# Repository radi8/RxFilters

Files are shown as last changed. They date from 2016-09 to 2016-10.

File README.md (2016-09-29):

# RxFilters

This is a first iteration of a set of high pass filters for a receiver. The filters are to be used in conjunction with the transmit low pass filters to form a bandpass filter which can be of variable width depending on the HP/LP combination selected. The advantage of this is that the Rx bandwidth can be wide (up to the Tx LP frequency) to enable skimming of frequencies up to the Tx frequency. I will be looking at diode switching of the filters in the future as this will give the option of developing smart filter switching to allow cross band operation etc. The receive can be a band set formed from a HP/LP combination and then when going to Tx the LP filter can be switched to match the Tx frequency and restored on receive.

This version is Relays only.

Notes:
The 1.8 MHz High Pass filter is in circuit by default all the time. In practise the broadcast signals are so strong that they can be received with the filter in. If full sensitivity operation in the broadcast and LF bands is desired then the filter is switched out and any appropriate filter switched in. Also with Hermes-Light the LNA gain can be reduced until clipping stops.

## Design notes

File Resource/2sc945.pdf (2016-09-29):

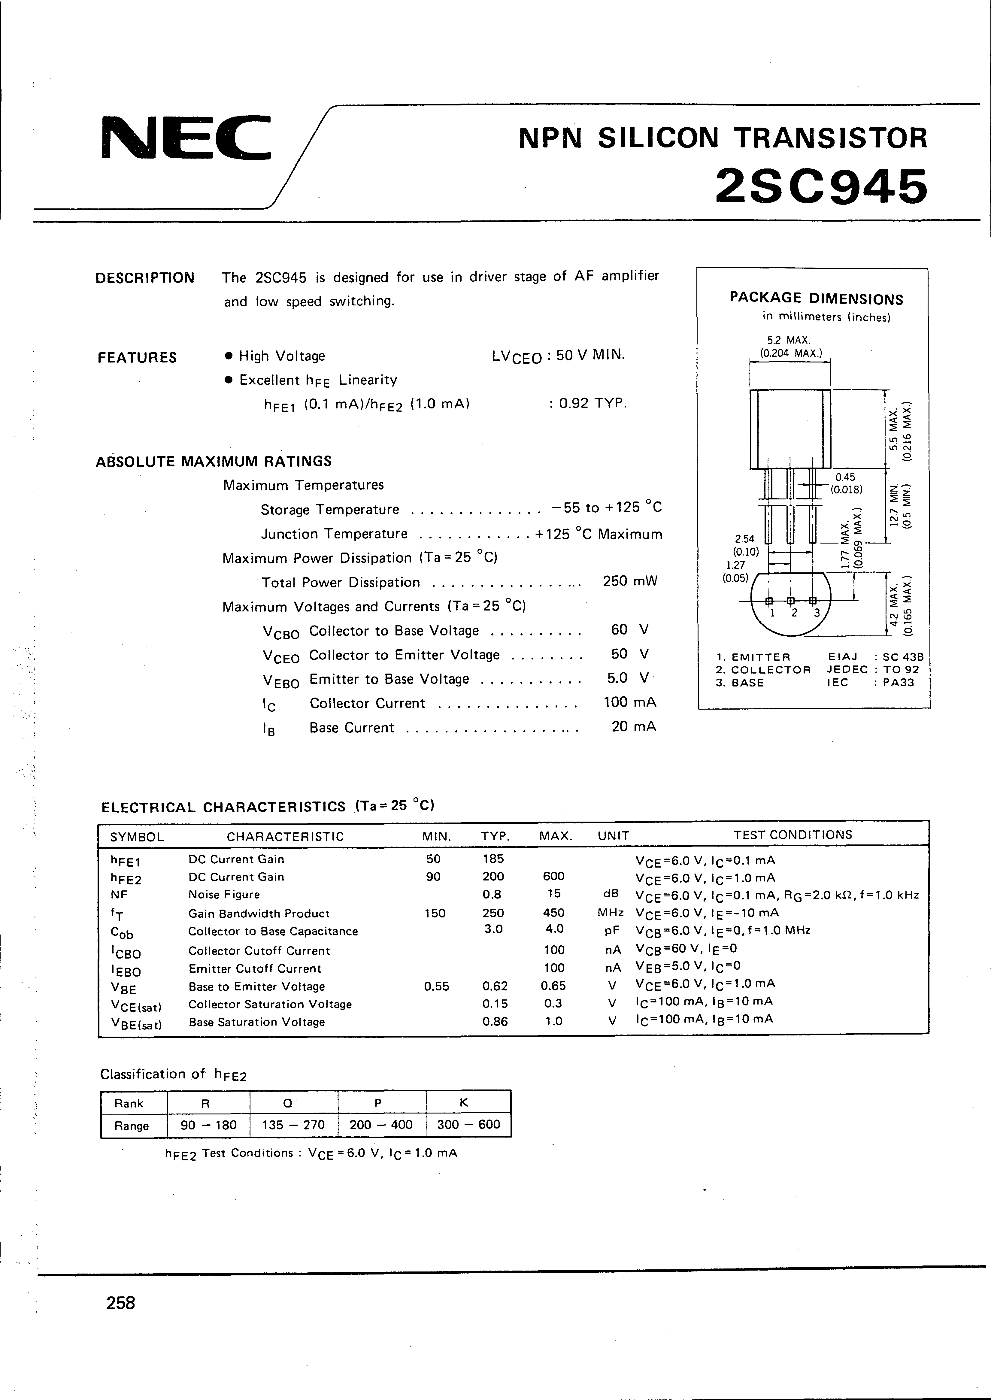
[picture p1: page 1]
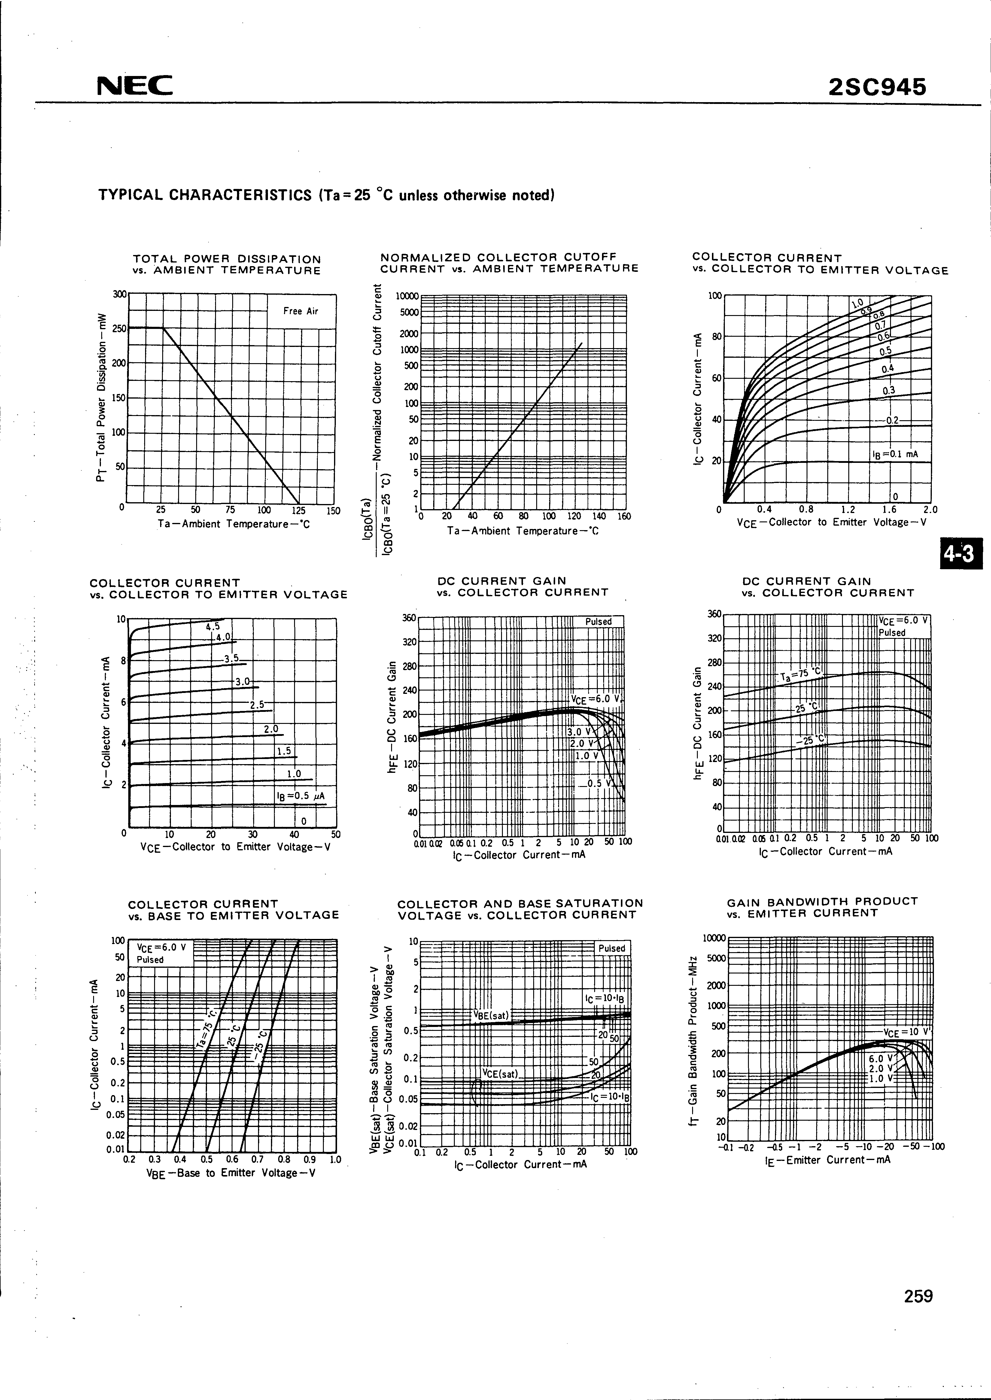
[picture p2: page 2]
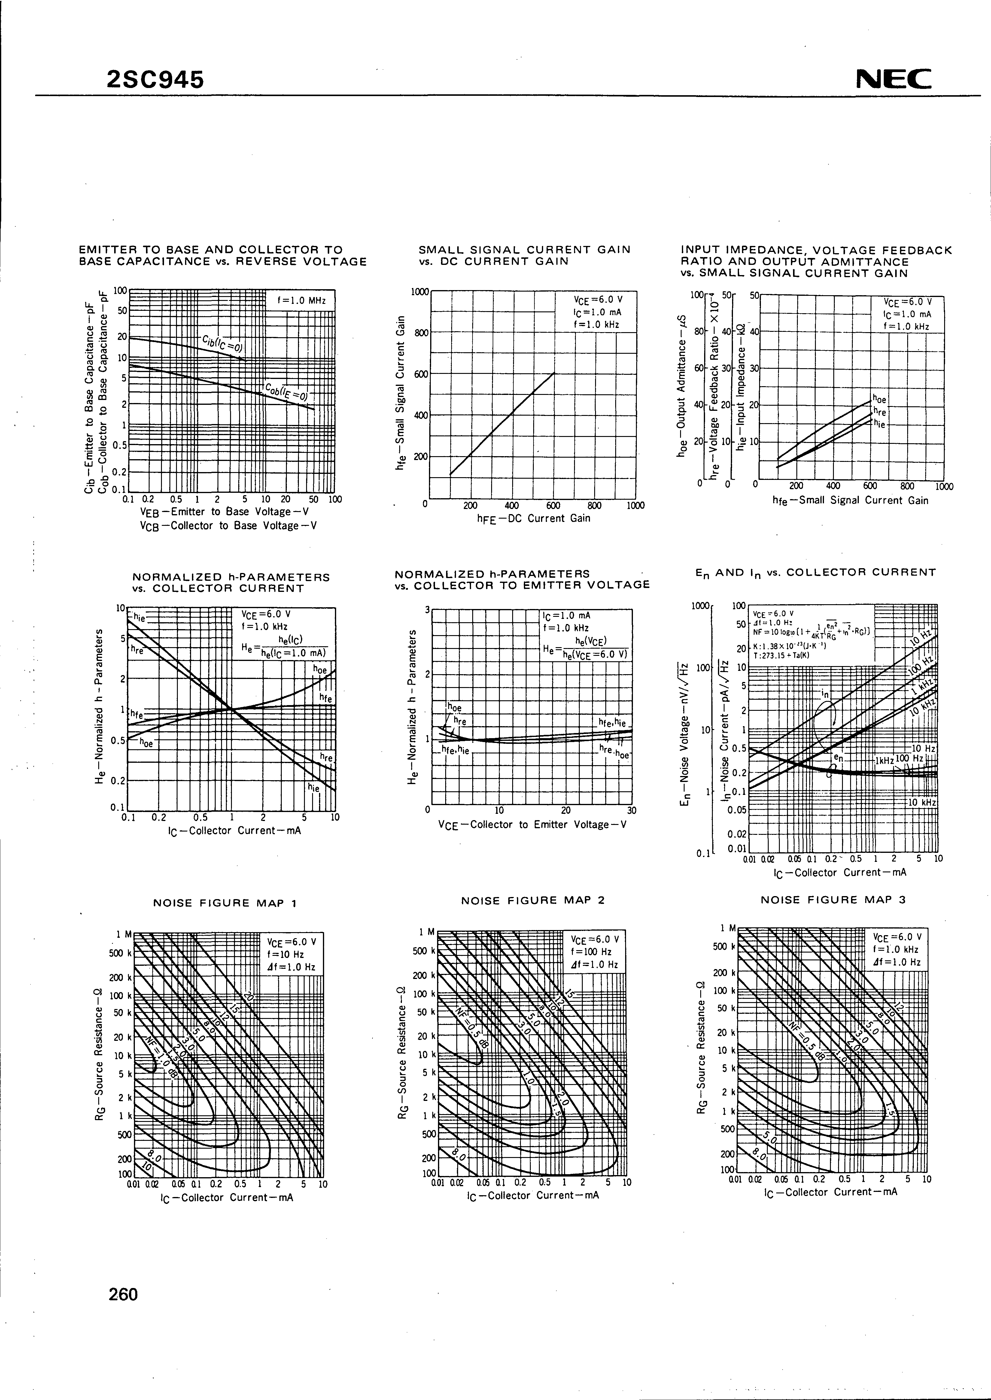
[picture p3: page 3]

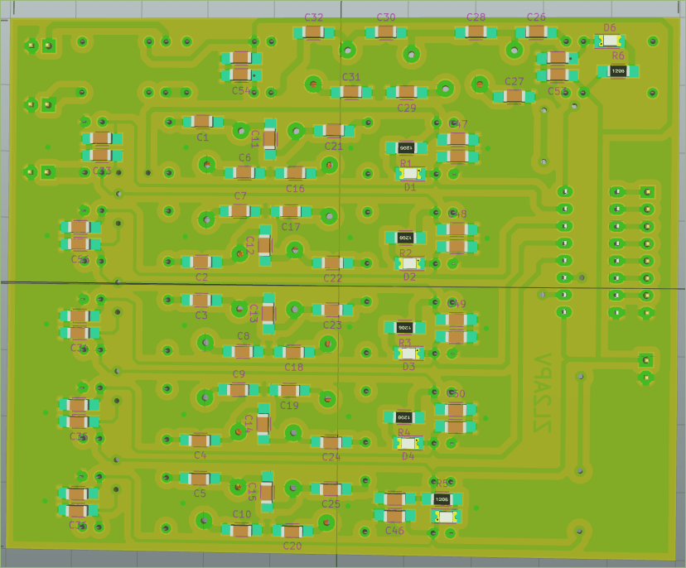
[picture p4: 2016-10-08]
Bottom Layout.png

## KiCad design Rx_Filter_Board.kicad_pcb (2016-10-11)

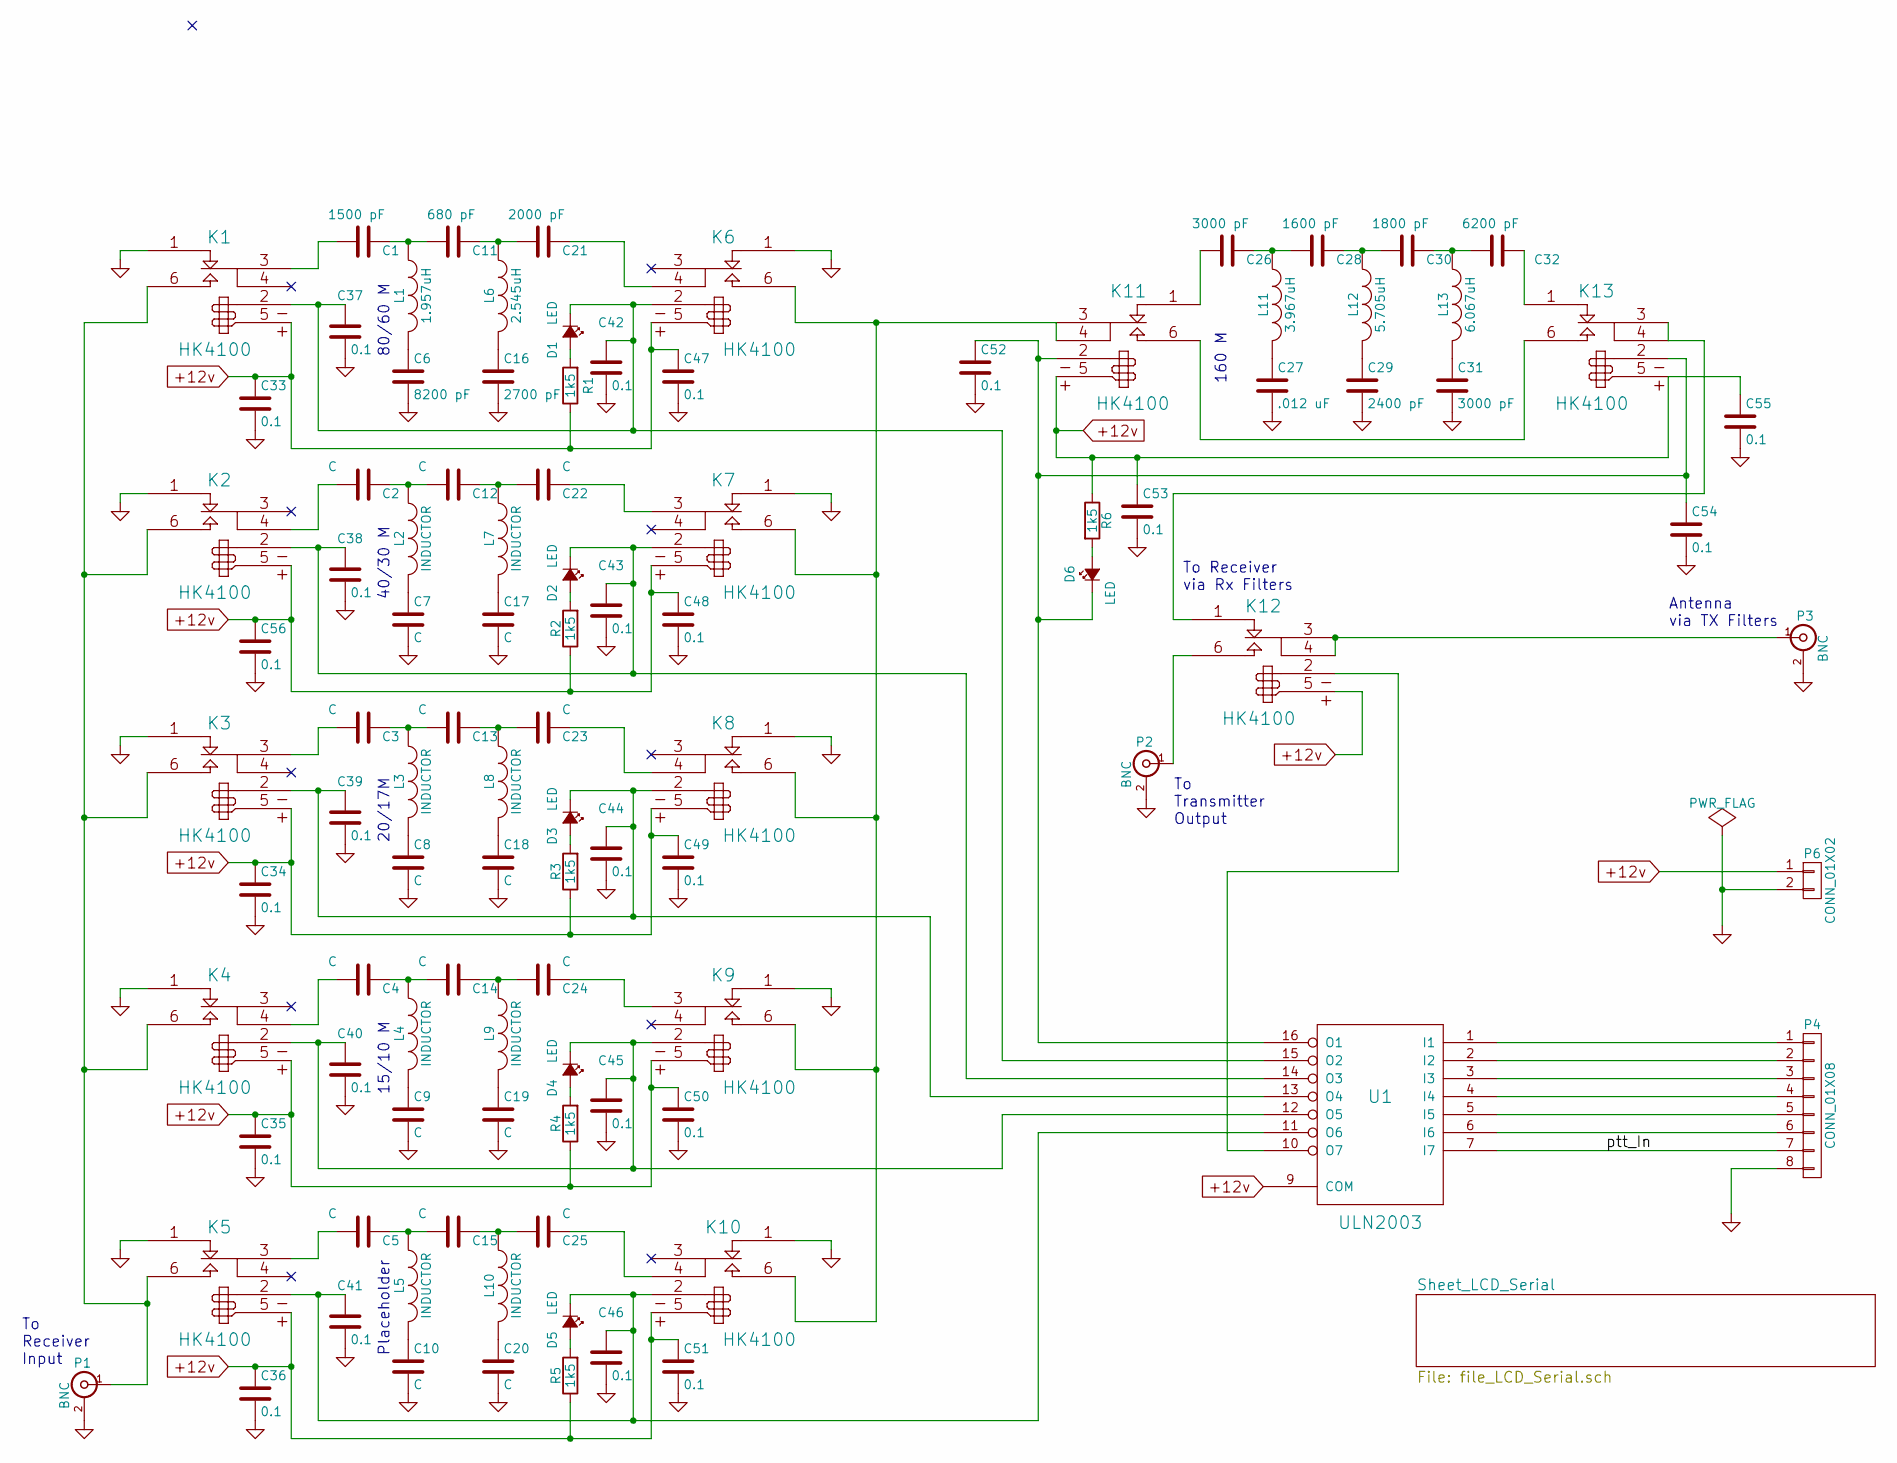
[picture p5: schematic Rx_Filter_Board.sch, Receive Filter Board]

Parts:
C1: 1500 pF; C_1206_HandSoldering
C2, C3, C4, C5, C7, C8, C9, C10, C12, C13, C14, C15, C17, C18, C19, C20, C22, C23, C24, C25: C; C_1206_HandSoldering
C6: 8200 pF; C_1206_HandSoldering
C11: 680 pF; C_1206_HandSoldering
C16: 2700 pF; C_1206_HandSoldering
C21: 2000 pF; C_1206_HandSoldering
C26, C31: 3000 pF; C_1206_HandSoldering
C27: .012 uF; C_1206_HandSoldering
C28: 1600 pF; C_1206_HandSoldering
C29: 2400 pF; C_1206_HandSoldering
C30: 1800 pF; C_1206_HandSoldering
C32: 6200 pF; C_1206_HandSoldering
C33, C34, C35, C36, C37, C38, C39, C40, C41, C42, C43, C44, C45, C46, C47, C48, C49, C50, C51, C52, C53, C54, C55, C56: 0.1; C_1206_HandSoldering
D1, D2, D3, D4, D5, D6: LED; LED_1206
K1, K2, K3, K4, K5, K6, K7, K8, K9, K10, K11, K12, K13: HK4100
L1: 1.957uH; Toroid_T37_Vertical
L2, L3, L4, L5, L7, L8, L9, L10: INDUCTOR; Toroid_T37_Vertical
L6: 2.545uH; Toroid_T37_Vertical
L11: 3.967uH; Toroid_T37_Vertical
L12: 5.705uH; Toroid_T37_Vertical
L13: 6.067uH; Toroid_T37_Vertical
P1, P2, P3: BNC; Pin_Header_Straight_1x02
P4: CONN_01X08; Pin_Header_Straight_1x08
P6: CONN_01X02; Pin_Header_Straight_1x02
R1, R2, R3, R4, R5, R6: 1k5; R_1206_HandSoldering
U1: ULN2003; DIP-16_W7.62mm_LongPads

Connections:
+12v: C33.1, C34.1, C35.1, C36.1, C47.1, C48.1, C49.1, C50.1, C51.1, C53.1, C55.1, C56.1, K1.5, K2.5, K3.5, K4.5, K5.5, K6.5, K7.5, K8.5, K9.5, K10.5, K11.5, K12.5, K13.5, P6.1, R1.1, R2.1, R3.1, R4.1, R5.1, R6.1, U1.9 (COM)
/ptt_In: P4.7, U1.7 (I7)
GND: C6.2, C7.2, C8.2, C9.2, C10.2, C16.2, C17.2, C18.2, C19.2, C20.2, C27.2, C29.2, C31.2, C33.2, C34.2, C35.2, C36.2, C37.2, C38.2, C39.2, C40.2, C41.2, C42.2, C43.2, C44.2, C45.2, C46.2, C47.2, C48.2, C49.2, C50.2, C51.2, C52.2, C53.2, C54.2, C55.2, C56.2, K1.1, K2.1, K3.1, K4.1, K5.1, K6.1, K7.1, K8.1, K9.1, K10.1, P1.2 (Ext), P2.2 (Ext), P3.2 (Ext), P4.8, P6.2, U1.8 (GND); also elsewhere on the board
unnamed: C1.1, C11.2, L1.1
unnamed: C1.2, K1.3
unnamed: C2.2, K2.4
unnamed: C3.2, K3.3
unnamed: C4.2, K4.4
unnamed: C5.2, K5.3
unnamed: C6.1, L1.2
unnamed: C7.1, L2.2
unnamed: C8.1, L3.2
unnamed: C9.1, L4.2
unnamed: C10.1, L5.2
unnamed: C11.1, C21.2, L6.1
unnamed: C12.1, C22.2, L7.1
unnamed: C2.1, C12.2, L2.1
unnamed: C13.1, C23.2, L8.1
unnamed: C3.1, C13.2, L3.1
unnamed: C14.1, C24.2, L9.1
unnamed: C4.1, C14.2, L4.1
unnamed: C15.1, C25.2, L10.1
unnamed: C5.1, C15.2, L5.1
unnamed: C16.1, L6.2
unnamed: C17.1, L7.2
unnamed: C18.1, L8.2
unnamed: C19.1, L9.2
unnamed: C20.1, L10.2
unnamed: C21.1, K6.4
unnamed: C22.1, K7.3
unnamed: C23.1, K8.4
unnamed: C24.1, K9.3
unnamed: C25.1, K10.4
unnamed: C26.1, C28.2, L11.1
unnamed: C26.2, K11.1
unnamed: C27.1, L11.2
unnamed: C28.1, C30.2, L12.1
unnamed: C29.1, L12.2
unnamed: C30.1, C32.2, L13.1
unnamed: C31.1, L13.2
unnamed: C32.1, K13.1
unnamed: C37.1, C42.1, D1.1 (K), K1.2, K6.2, U1.15 (O2)
unnamed: C38.1, C43.1, D2.1 (K), K2.2, K7.2, U1.14 (O3)
unnamed: C39.1, C44.1, D3.1 (K), K3.2, K8.2, U1.13 (O4)
unnamed: C40.1, C45.1, D4.1 (K), K4.2, K9.2, U1.12 (O5)
unnamed: C41.1, C46.1, D5.1 (K), K5.2, K10.2, U1.11 (O6)
unnamed: C52.1, C54.1, D6.1 (K), K11.2, K13.2, U1.16 (O1)
unnamed: D1.2 (A), R1.2
unnamed: D2.2 (A), R2.2
unnamed: D3.2 (A), R3.2
unnamed: D4.2 (A), R4.2
unnamed: D5.2 (A), R5.2
unnamed: D6.2 (A), R6.2
unnamed: K1.6, K2.6, K3.6, K4.6, K5.6, P1.1 (In)
unnamed: K6.6, K7.6, K8.6, K9.6, K10.6, K11.3, K11.4
unnamed: K11.6, K13.6
unnamed: K12.1, K13.3, K13.4
unnamed: K12.2, U1.10 (O7)
unnamed: K12.3, K12.4, P3.1 (In)
unnamed: K12.6, P2.1 (In)
unnamed: P4.1, U1.1 (I1)
unnamed: P4.2, U1.2 (I2)
unnamed: P4.3, U1.3 (I3)
unnamed: P4.4, U1.4 (I4)
unnamed: P4.5, U1.5 (I5)
unnamed: P4.6, U1.6 (I6)

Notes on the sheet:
To Receiver via Rx Filters
Antenna via TX Filters
160 M
40/30 M
20/17M
15/10 M
80/60 M
To Receiver Input
To Transmitter Output
Placeholder

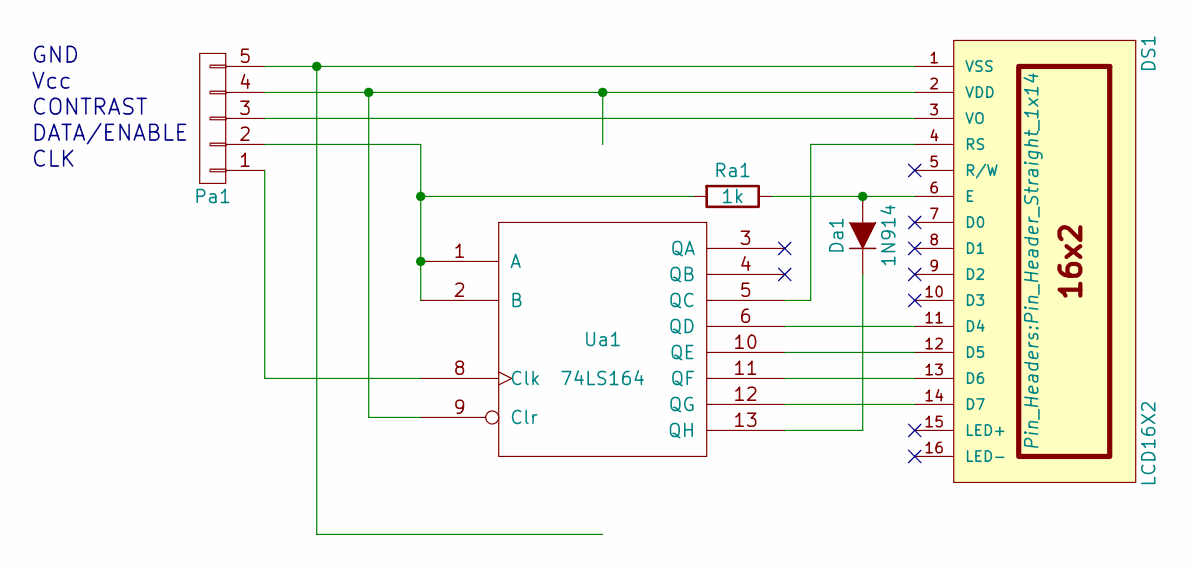
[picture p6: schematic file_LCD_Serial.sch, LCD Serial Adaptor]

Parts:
DS1: LCD16X2; Pin_Header_Straight_1x14
Da1: 1N914; Diode_DO-35_SOD27_Horizontal_RM10
Pa1: CONN_01X05; Pin_Header_Straight_1x05
Ra1: 1k; R_1206_HandSoldering
Ua1: 74LS164; DIP-14_W7.62mm_LongPads

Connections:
unnamed 53: DS1.3 (VO), Pa1.3; also elsewhere on the board
unnamed 54: DS1.4 (RS), Ua1.5 (QC); also elsewhere on the board
unnamed 55: DS1.6 (E), Da1.2 (A), Ra1.1; also elsewhere on the board
unnamed 56: DS1.11 (D4), Ua1.6 (QD); also elsewhere on the board
unnamed 57: DS1.12 (D5), Ua1.10 (QE); also elsewhere on the board
unnamed 58: DS1.13 (D6), Ua1.11 (QF); also elsewhere on the board
unnamed 59: DS1.14 (D7), Ua1.12 (QG); also elsewhere on the board
unnamed 60: Da1.1 (K), Ua1.13 (QH); also elsewhere on the board
unnamed 74: Pa1.1, Ua1.8 (Clk); also elsewhere on the board
unnamed 75: Pa1.2, Ra1.2, Ua1.1 (A), Ua1.2 (B); also elsewhere on the board

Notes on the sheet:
GND
Vcc
CONTRAST
DATA/ENABLE
CLK

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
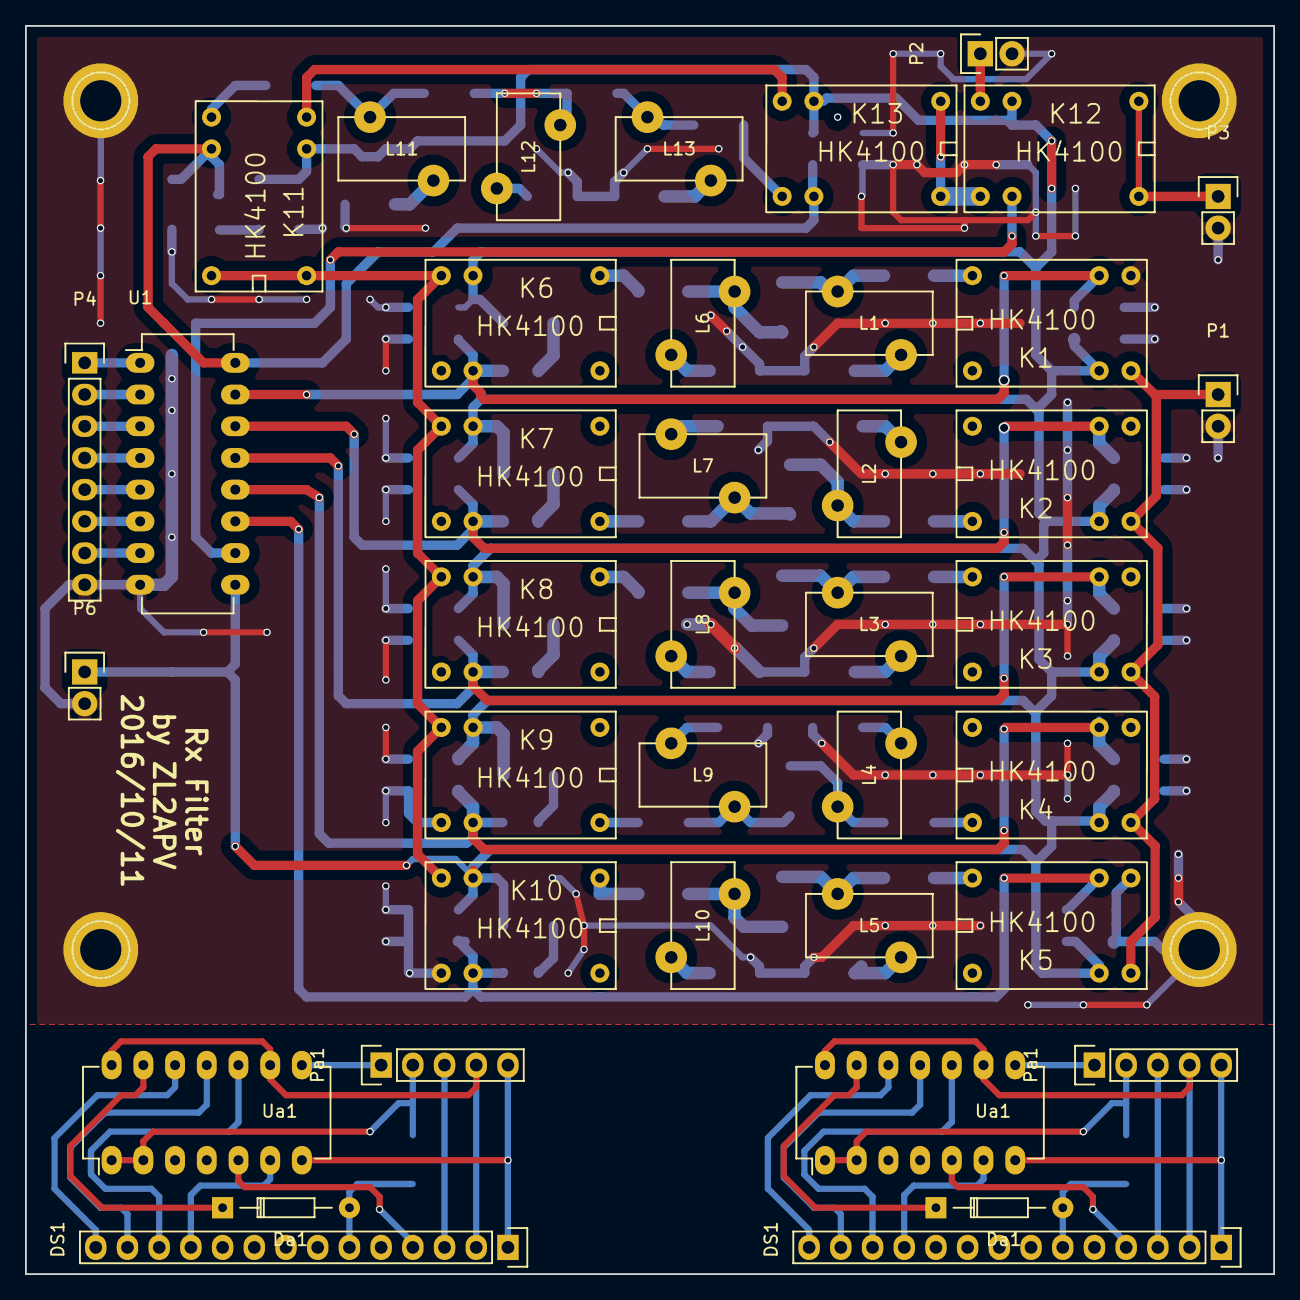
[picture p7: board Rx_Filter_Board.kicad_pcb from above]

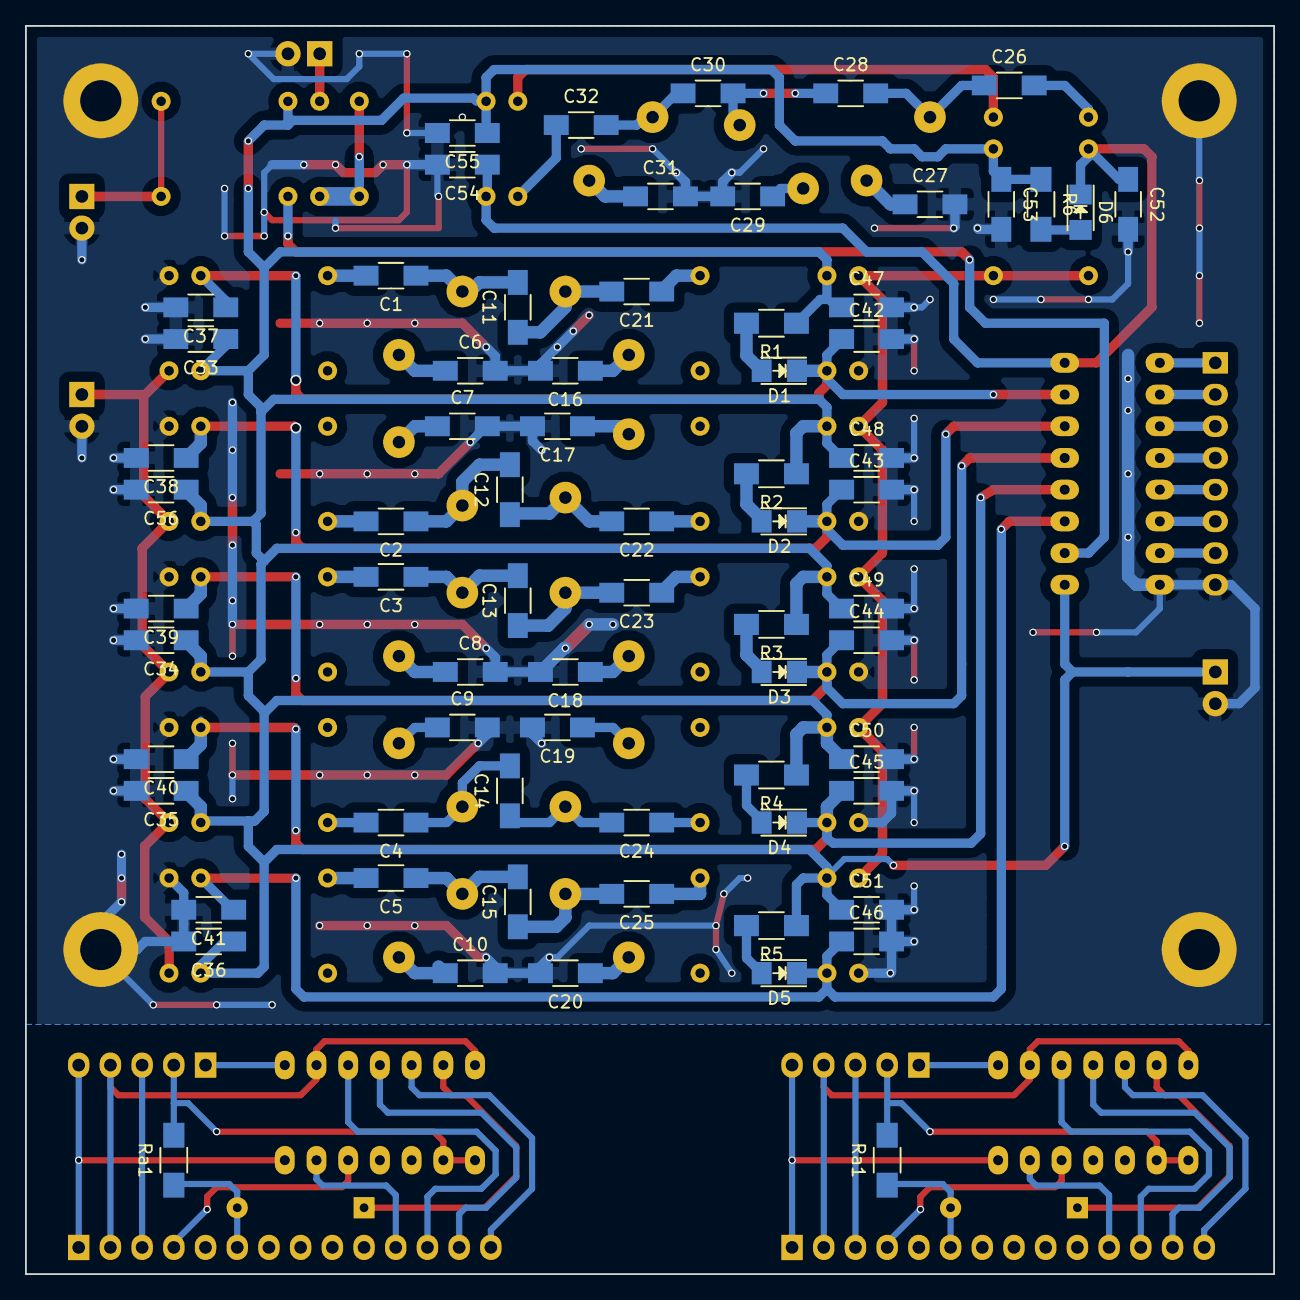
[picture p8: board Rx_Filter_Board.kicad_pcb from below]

Board: 2 copper layers, 100.0 x 100.0 mm, 114 parts (70 on the bottom side), 78 nets.

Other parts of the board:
CNR1, CNR2, CNR3: 1pin
CVR4: 1pin
DS1#2: LCD16X2; Pin_Header_Straight_1x14
Da1#2: 1N914; Diode_DO-35_SOD27_Horizontal_RM10
Pa1#2: CONN_01X05; Pin_Header_Straight_1x05
Ra1#2: 1k; R_1206_HandSoldering
Ua1#2: 74LS164; DIP-14_W7.62mm_LongPads

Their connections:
GND: CNR1.1, CNR2.1, CNR3.1, CVR4.1; also elsewhere on the board
unnamed 53: DS1#2.3, Pa1#2.3; also elsewhere on the board
unnamed 54: DS1#2.4, Ua1#2.5; also elsewhere on the board
unnamed 55: DS1#2.6, Da1#2.2, Ra1#2.1; also elsewhere on the board
unnamed 56: DS1#2.11, Ua1#2.6; also elsewhere on the board
unnamed 57: DS1#2.12, Ua1#2.10; also elsewhere on the board
unnamed 58: DS1#2.13, Ua1#2.11; also elsewhere on the board
unnamed 59: DS1#2.14, Ua1#2.12; also elsewhere on the board
unnamed 60: Da1#2.1, Ua1#2.13; also elsewhere on the board
unnamed 74: Pa1#2.1, Ua1#2.8; also elsewhere on the board
unnamed 75: Pa1#2.2, Ra1#2.2, Ua1#2.1, Ua1#2.2; also elsewhere on the board

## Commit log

2016-09-30 First cut at filter circuit
    [Rx_Filter_Board.sch]
2016-09-30 Some layout tweaks only
    [Rx_Filter_Board.sch]
2016-10-06 Board at 1st layout stage
    [Rx_Filter_Board.kicad_pcb, Rx_Filter_Board.sch]
2016-10-06 Setting up ground plane
    [Rx_Filter_Board.kicad_pcb]
2016-10-07 A usable board at this point
    [Rx_Filter_Board.kicad_pcb, Rx_Filter_Board.sch]
2016-10-08 Saving home brew lazer board layout in branch Hbrew
    [Rx_Filter_Board.kicad_pcb]
2016-10-09 Filter progress
    [Rx_Filter_Board.kicad_pcb]
2016-10-10 Layout completed
    [Rx_Filter_Board.kicad_pcb]
2016-10-11 Final fabrication with LCD serial driver added
    [Rx_Filter_Board-B.Cu.gbr, Rx_Filter_Board-B.Mask.gbr, Rx_Filter_Board-B.SilkS.gbr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]
